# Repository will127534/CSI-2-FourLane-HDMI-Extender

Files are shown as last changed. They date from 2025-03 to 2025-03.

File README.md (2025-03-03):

# CSI-2-FourLane-HDMI-Extender
A simple MIPI CSI-2 extender with 4-lane support through HDMI cable

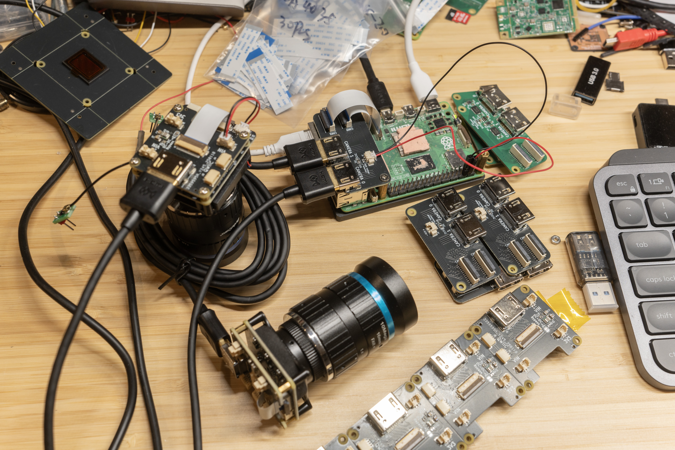
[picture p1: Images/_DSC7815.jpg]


## Hardware
Technically, this isn’t supposed to work, but it kind of does. It relies on HDMI cables with Ethernet support to provide the fifth differential pair needed to transmit 4-lane MIPI signals through the HDMI cable.

The board is very simple. The receiver can either use the 3.3V from the FPC cable or an external power input to supply the HDMI connector’s power output. The HDMI connector location matches the USB connector on the Raspberry Pi 5 to simplify case design.

The transmitter board has a DC-DC step-down converter with a 3.3V output and a bypass option to power camera boards. For the StarlightEye (which needs a 5V input), there is also a connector that taps into the HDMI power input to supply power—this could also power something else, like an LED light source. Additionally, there is a QWIIC connector for sideband communication. Finally, the board’s form factor includes a cutout for the OneInchEye 2.0.

## Notes

This project came about because GMSL2 was too difficult to implement, and I needed something to extend my 4-lane MIPI cameras. If you’re reading this, you probably already know there are a few HDMI extender boards for MIPI cameras out there. However, most only support 2-lane MIPI, while I specifically needed 4-lane MIPI.

Where’s the catch? The standard HDMI cable only has four high-speed differential pairs, so that’s typically not enough for 4-lane MIPI (which requires 4 data pairs + 1 clock pair). However, HDMI includes an extension standard that reuses the HPD and UTILITY pins on the connector for a fifth differential pair called HEAC. This pair is meant for a bi-directional higher-speed sideband signal for Ethernet or Audio. Spec-wise, it doesn't have to carry signals as high-speed as the main video data. However, from a manufacturing standpoint, it’s often just as capable, because many manufacturers use the same type of differential pair cable for the fifth pair. (See [this teardown video by ChargerLab ](https://www.youtube.com/watch?v=UTeQvG3jk0k) as an example.)

For testing, I used the Cable Matters 2-Pack Ultra Thin HDMI Cable series; the 6-ft version is the maximum length that can run both the OneInchEye and StarlightEye at 1440 Mbps/lane with 4-lane MIPI.

Note: If you are using my IMX585 driver, you must lower the link speed from 1782 Mbps/lane to 1440 Mbps/lane by changing [this](https://github.com/will127534/imx585-v4l2-driver/blob/main/imx585.c#L210) line to 0x03.

Lastly, I did try using MIPI redrivers and retimers from [Ti](https://www.ti.com/product/SN65DPHY440SS) and [Diodes](https://www.diodes.com/part/view/PI2MEQX2505). The receiver board was originally designed with an active redriver/retimer (both parts are conveniently pin-to-pin compatible). However, due to the board’s pin layout, the differential pairs would need a polarity swap, and TI’s retimer wouldn’t work, even with [this register](https://e2e.ti.com/support/interface-group/interface/f/interface-forum/1187578/sn65dphy440ss-in-a-csi-application-is-it-possible-to-invert-n-and-p-on-both-sides-of-t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) configured. As for the redriver, for some reason I couldn’t get it to work well with a 6-ft cable—only with a very short HDMI cable. The redriver is polarity-invariant, but even after playing around with the different tuning options, it just didn’t seem to work reliably. Suggestions are welcome in the issues/comments section.

## Footnotes

* Gerber, BOM, and CPL files for JLCPCB are under /Gerber and /bom in each Transmitter and Receiver board folder.
* [Interactive BOM for Receiver](https://htmlpreview.github.io/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) [(provided by InteractiveHtmlBom)
](https://github.com/openscopeproject/InteractiveHtmlBom)
* [Interactive BOM for Transmitter](https://htmlpreview.github.io/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) [(provided by InteractiveHtmlBom)
](https://github.com/openscopeproject/InteractiveHtmlBom)
* Yes It still supports 2-lane MIPI cameras (tested with the IMX708 Raspberry Pi Camera V3).
* I have almost no intention of selling this on Tindie, because I can already imagine users who don’t fully understand the details running into troubles and complaining about it.
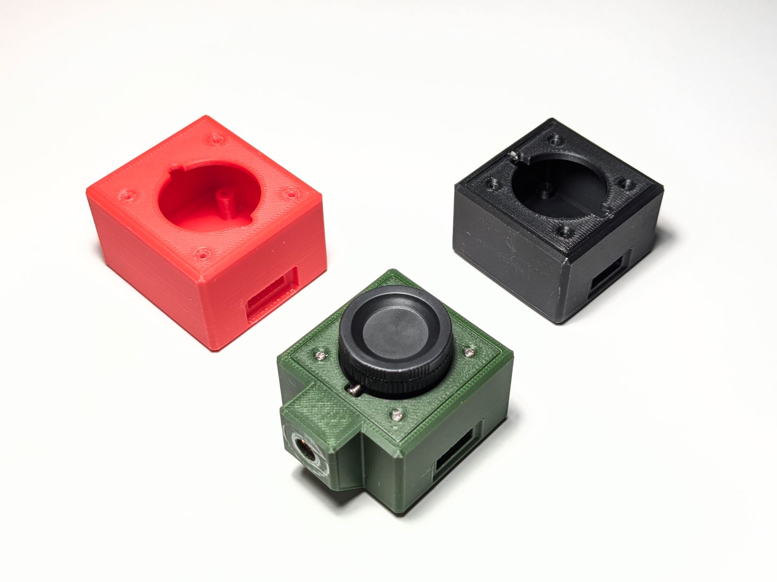
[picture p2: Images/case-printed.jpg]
* [@VoeGalore](https://github.com/VoeGalore/CSI-2-FourLane-HDMI-Extender) made 3D-printable cases for using the transmitter board with starlighteye(IMX585), oneincheye(IMX283), and Camera Module V3. STL files are under /case-STL in each folders. Additional hardware might be needed (M2x16 screws, M2x6 screws, M2 threaded insert, 1/4-20 threaded insert).

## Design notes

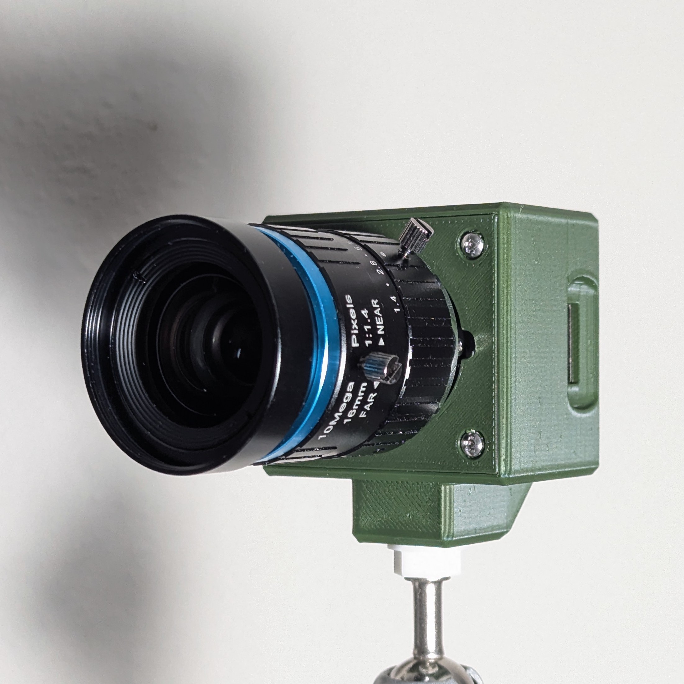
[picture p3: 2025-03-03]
Images/case-starlighteye-mounted.jpg

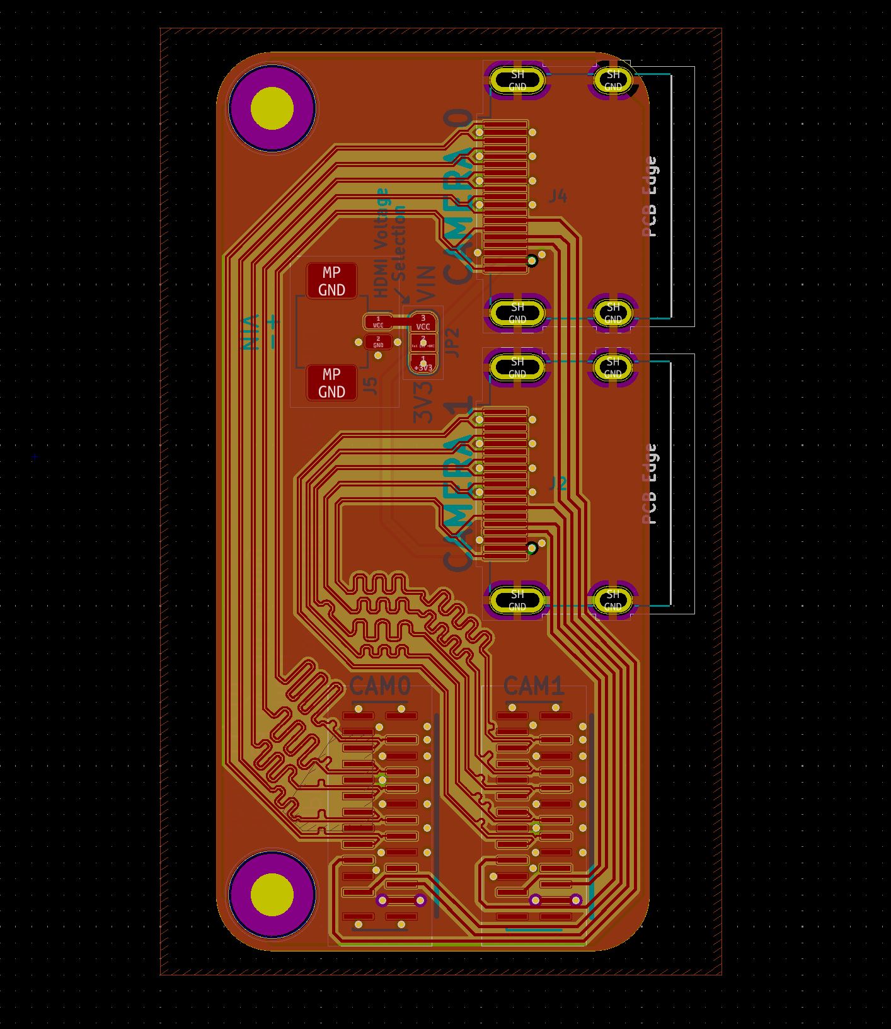
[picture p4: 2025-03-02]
Receiver/PCB.jpg

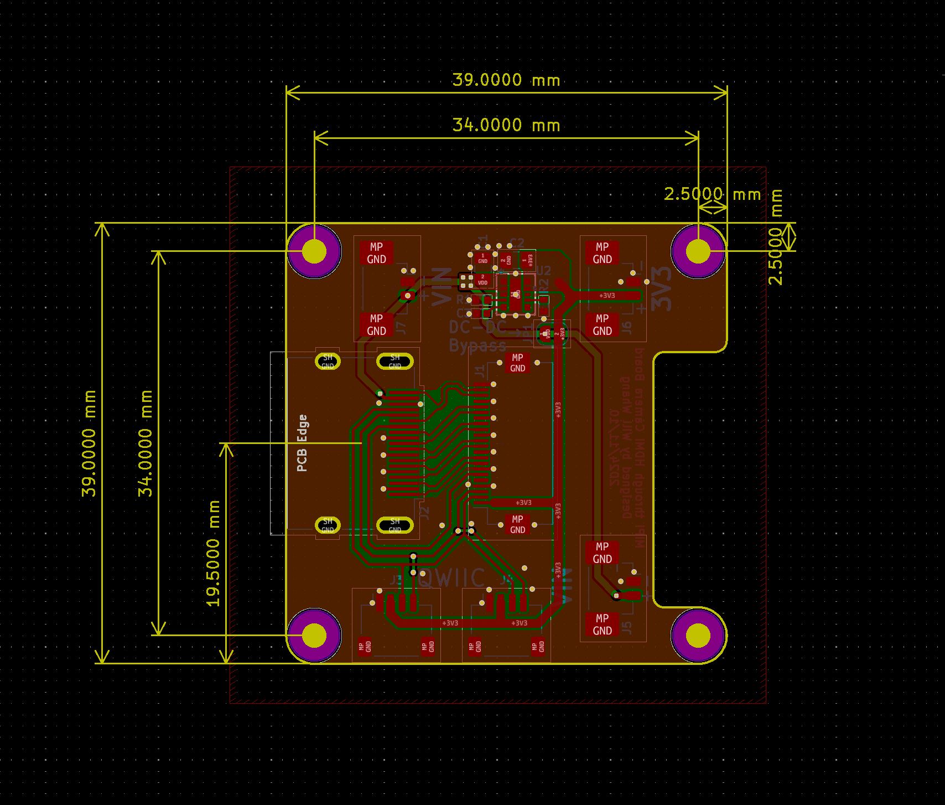
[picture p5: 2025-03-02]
Transmitter/PCB.jpg

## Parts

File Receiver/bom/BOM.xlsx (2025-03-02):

Comment | Designator | Footprint | JLCPCB Part #（optional）
HDMI-019S | J4,J2 | HDMI_A_Molex_208658-1001_Horizontal | C111617
Conn_01x22_Shielded | J1,J3 | TF3822S05SV830 | C6552695
Conn_01x02_Shielded | J5 | Molex_PicoBlade_53261-0271_1x02-1MP_P1.25mm_Horizontal | C177225

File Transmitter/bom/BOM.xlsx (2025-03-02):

Comment | Designator | Footprint | JLCPCB Part #（optional）
Conn_01x02_Shielded | J7,J6,J5 | Molex_PicoBlade_53398-0271_1x02-1MP_P1.25mm_Vertical | C122410
Conn_01x04_Shielded | J4,J3 | JST_SH_SM04B-SRSS-TB_1x04-1MP_P1.00mm_Horizontal | C160404
TPSM82902SISR | U2 | uSIP11_SIS_TEX | C6339351
Conn_01x22_Shielded | J1 | Hirose_FH12-22S-0.5SH_1x22-1MP_P0.50mm_Horizontal | C597981
40.2K | R1 | R_0402_1005Metric
22uF | C2 | C_0805_2012Metric
10uF | C3 | C_0402_1005Metric
10uF | C1 | C_0805_2012Metric
HDMI_A_1.4 | J2 | HDMI_A_Molex_208658-1001_Horizontal | C111617

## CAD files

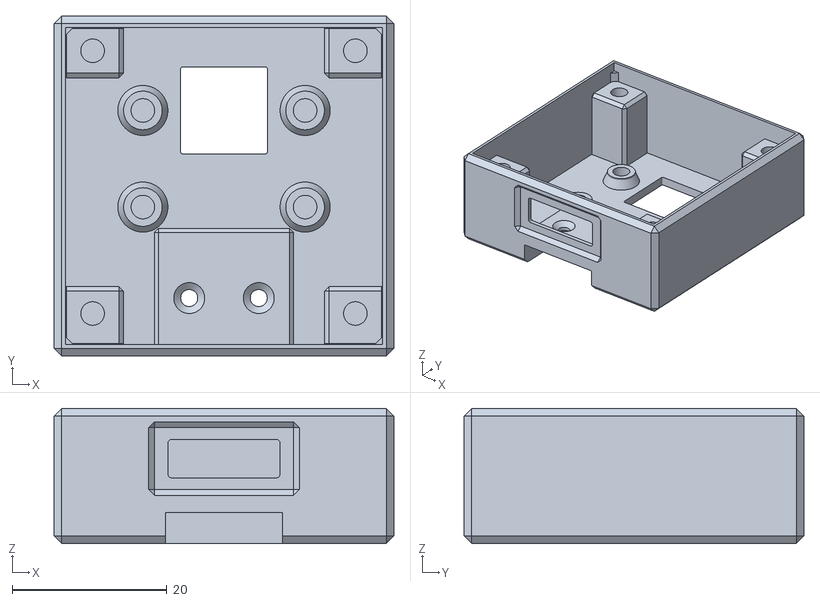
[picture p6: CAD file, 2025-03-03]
case-STL/cameraV3/Case for V3 - main.stl
44.0 x 44.0 x 17.5

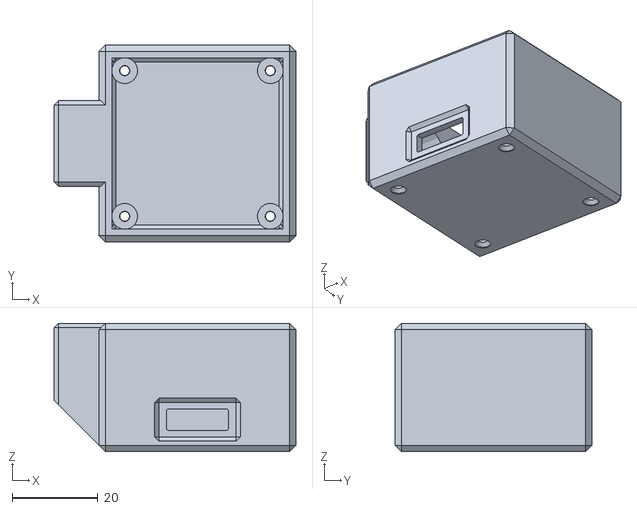
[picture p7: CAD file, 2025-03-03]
case-STL/oneincheye/case for oneincheye - high standoff - with 1_4-20 mounting.stl
56.5 x 46.0 x 30.0

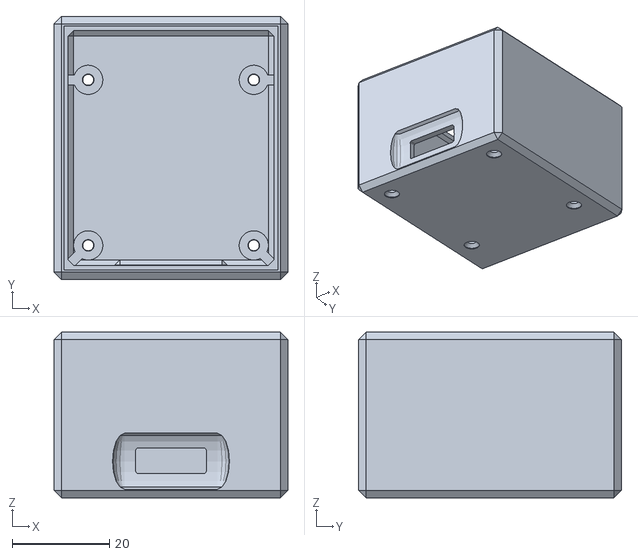
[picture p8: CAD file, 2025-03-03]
case-STL/starlighteye/case for starlighteye.stl
48.0 x 54.0 x 34.0

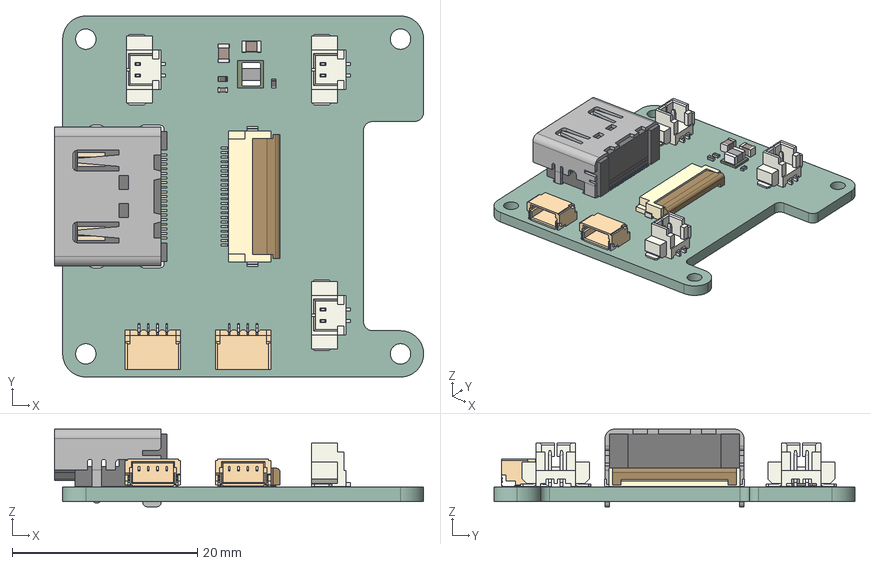
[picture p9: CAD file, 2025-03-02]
Transmitter/Transmitter.step
39.9 x 39.0 x 8.39 mm
Molex_53398_0271 x 3
SM04B-SRSS-TB(LFSN) x 2
R_0402_1005Metric x 2
SIS0011A_ASM
Hirose_FH12_xxS_0_5SH_Parametric_v0_1
C_0805_2012Metric x 2
C_0402_1005Metric
HDMI_A_Molex_208658-1001_Horizontal
MIPItoHDMI_Buffered_PCB

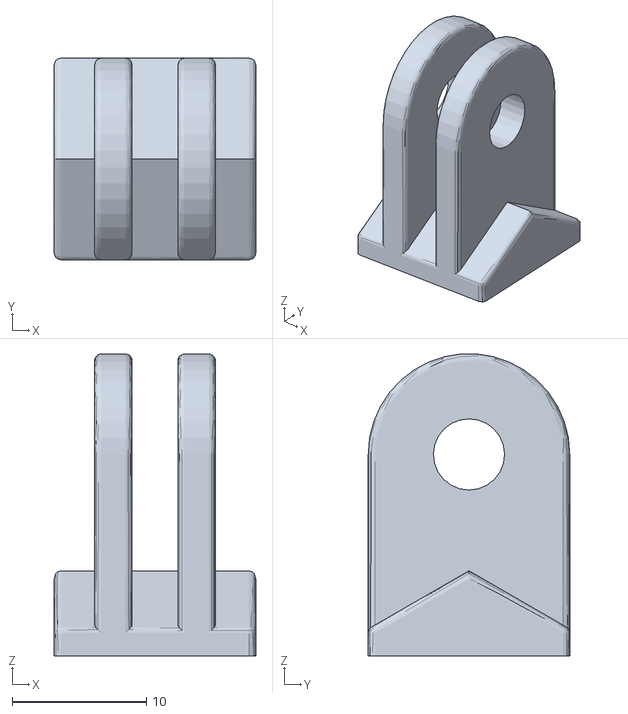
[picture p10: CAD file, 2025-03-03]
case-STL/cameraV3/Case for V3 - gopro mount ear.stl
15.0 x 15.0 x 22.5

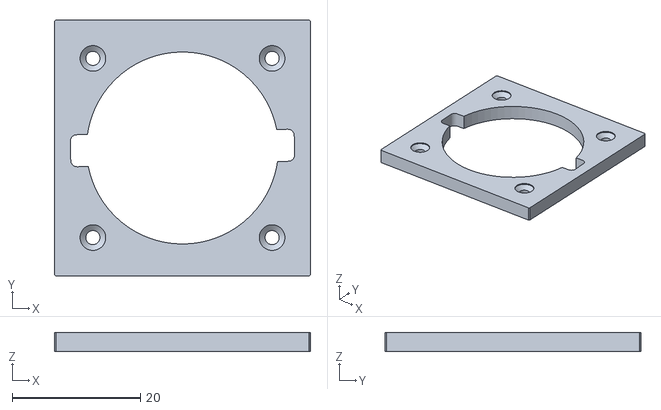
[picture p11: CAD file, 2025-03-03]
case-STL/oneincheye/faceplate for oneincheye.stl
40.0 x 40.0 x 3.00

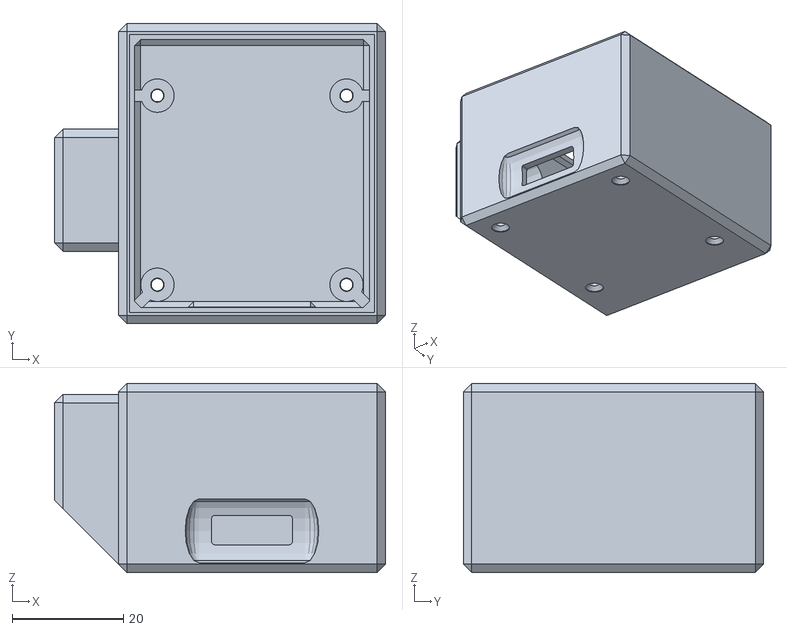
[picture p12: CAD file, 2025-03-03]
case-STL/starlighteye/case for starlighteye - with 1_4-20 mounting.stl
59.5 x 54.0 x 34.0

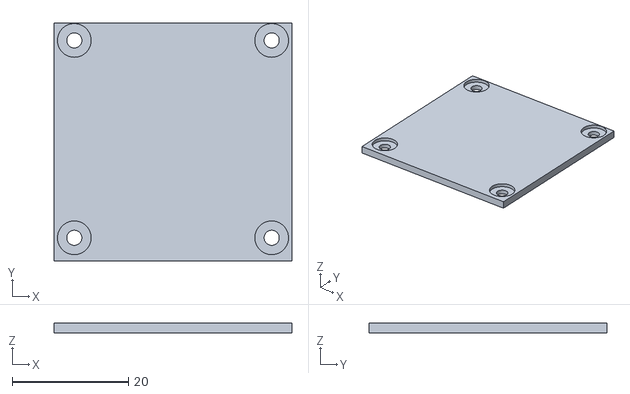
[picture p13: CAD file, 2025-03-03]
case-STL/cameraV3/Case for V3 - backplate.stl
41.0 x 41.0 x 1.70

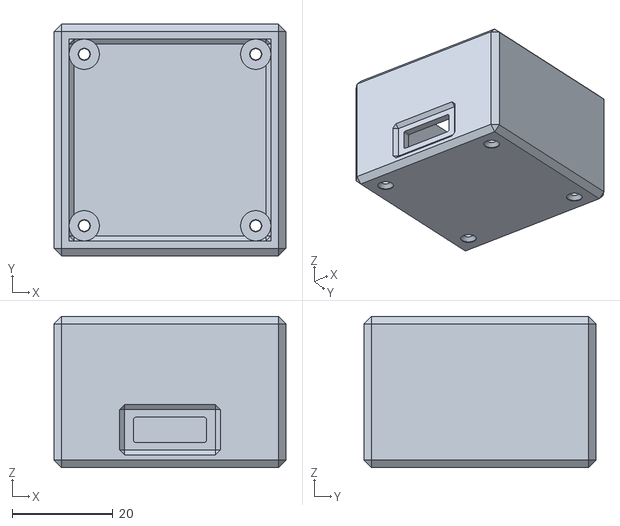
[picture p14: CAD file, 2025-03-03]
case-STL/oneincheye/case for oneincheye - high standoff.stl
46.0 x 46.0 x 30.0

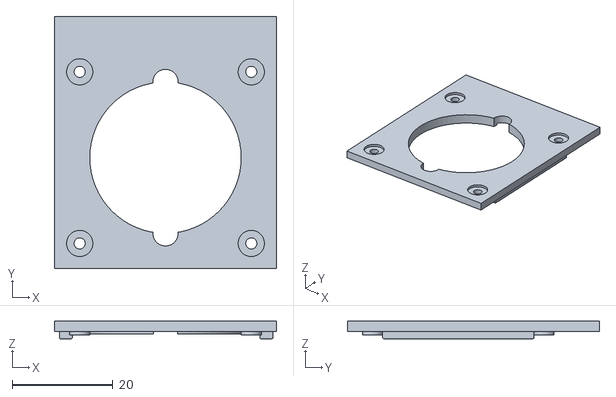
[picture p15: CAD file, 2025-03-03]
case-STL/starlighteye/faceplate for starlighteye.stl
44.0 x 50.0 x 3.50

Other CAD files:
case-STL/oneincheye/case for oneincheye - low standoff.stl

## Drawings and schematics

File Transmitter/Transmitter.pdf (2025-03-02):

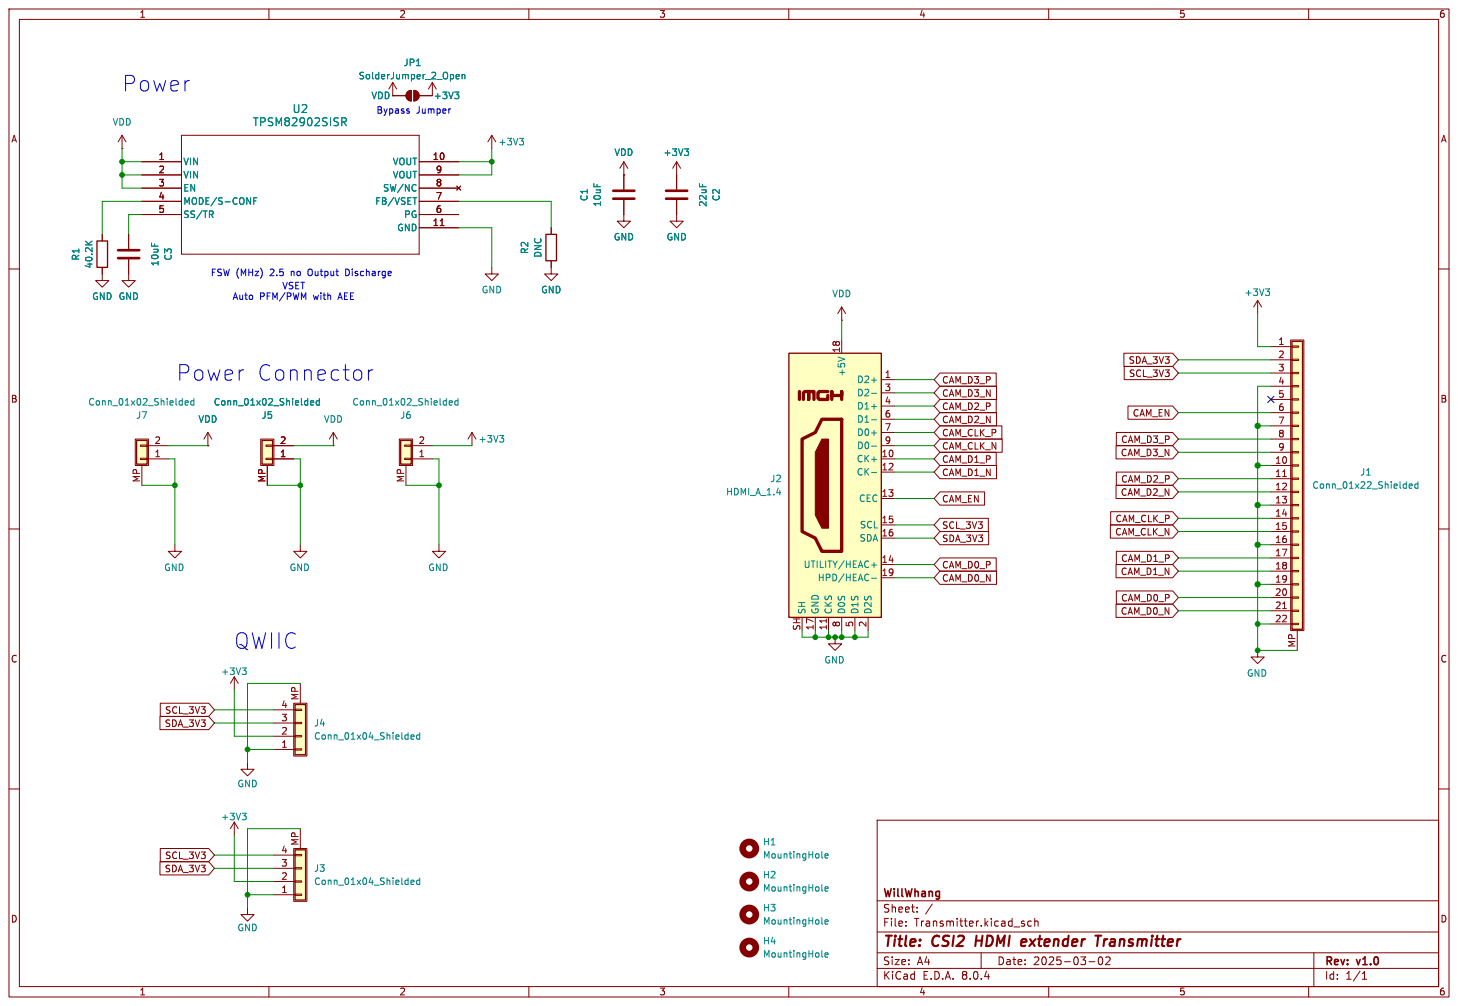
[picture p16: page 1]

Bypass Jumper VSET Auto PFM/PWM with AEE U2 TPSM82902SISR

FSW (MHz) 2.5 no Output Discharge

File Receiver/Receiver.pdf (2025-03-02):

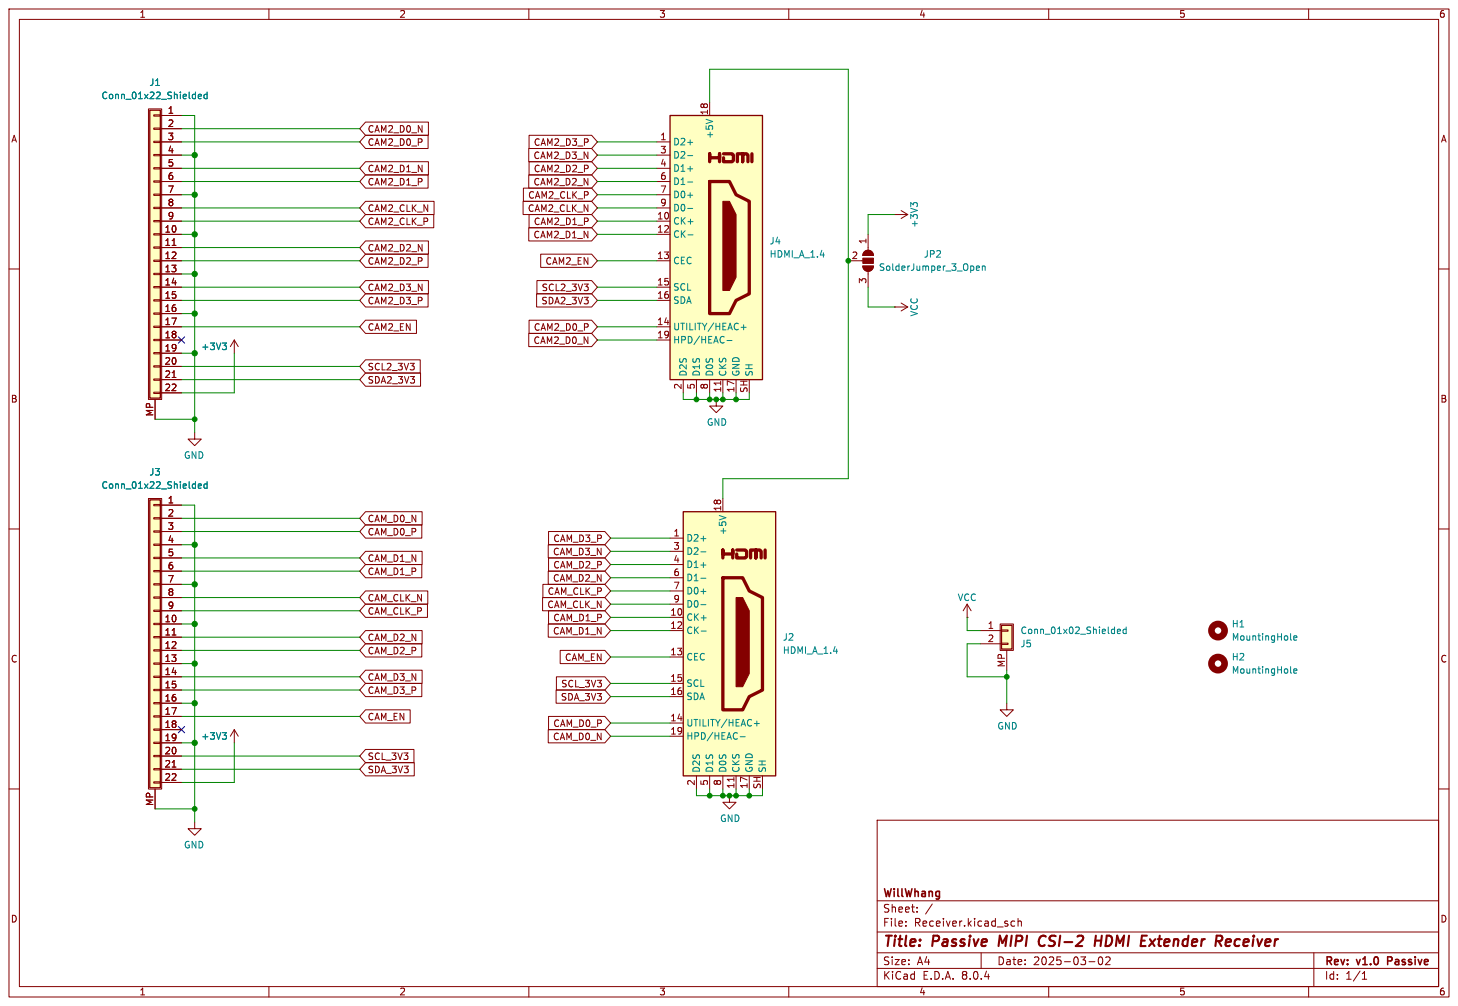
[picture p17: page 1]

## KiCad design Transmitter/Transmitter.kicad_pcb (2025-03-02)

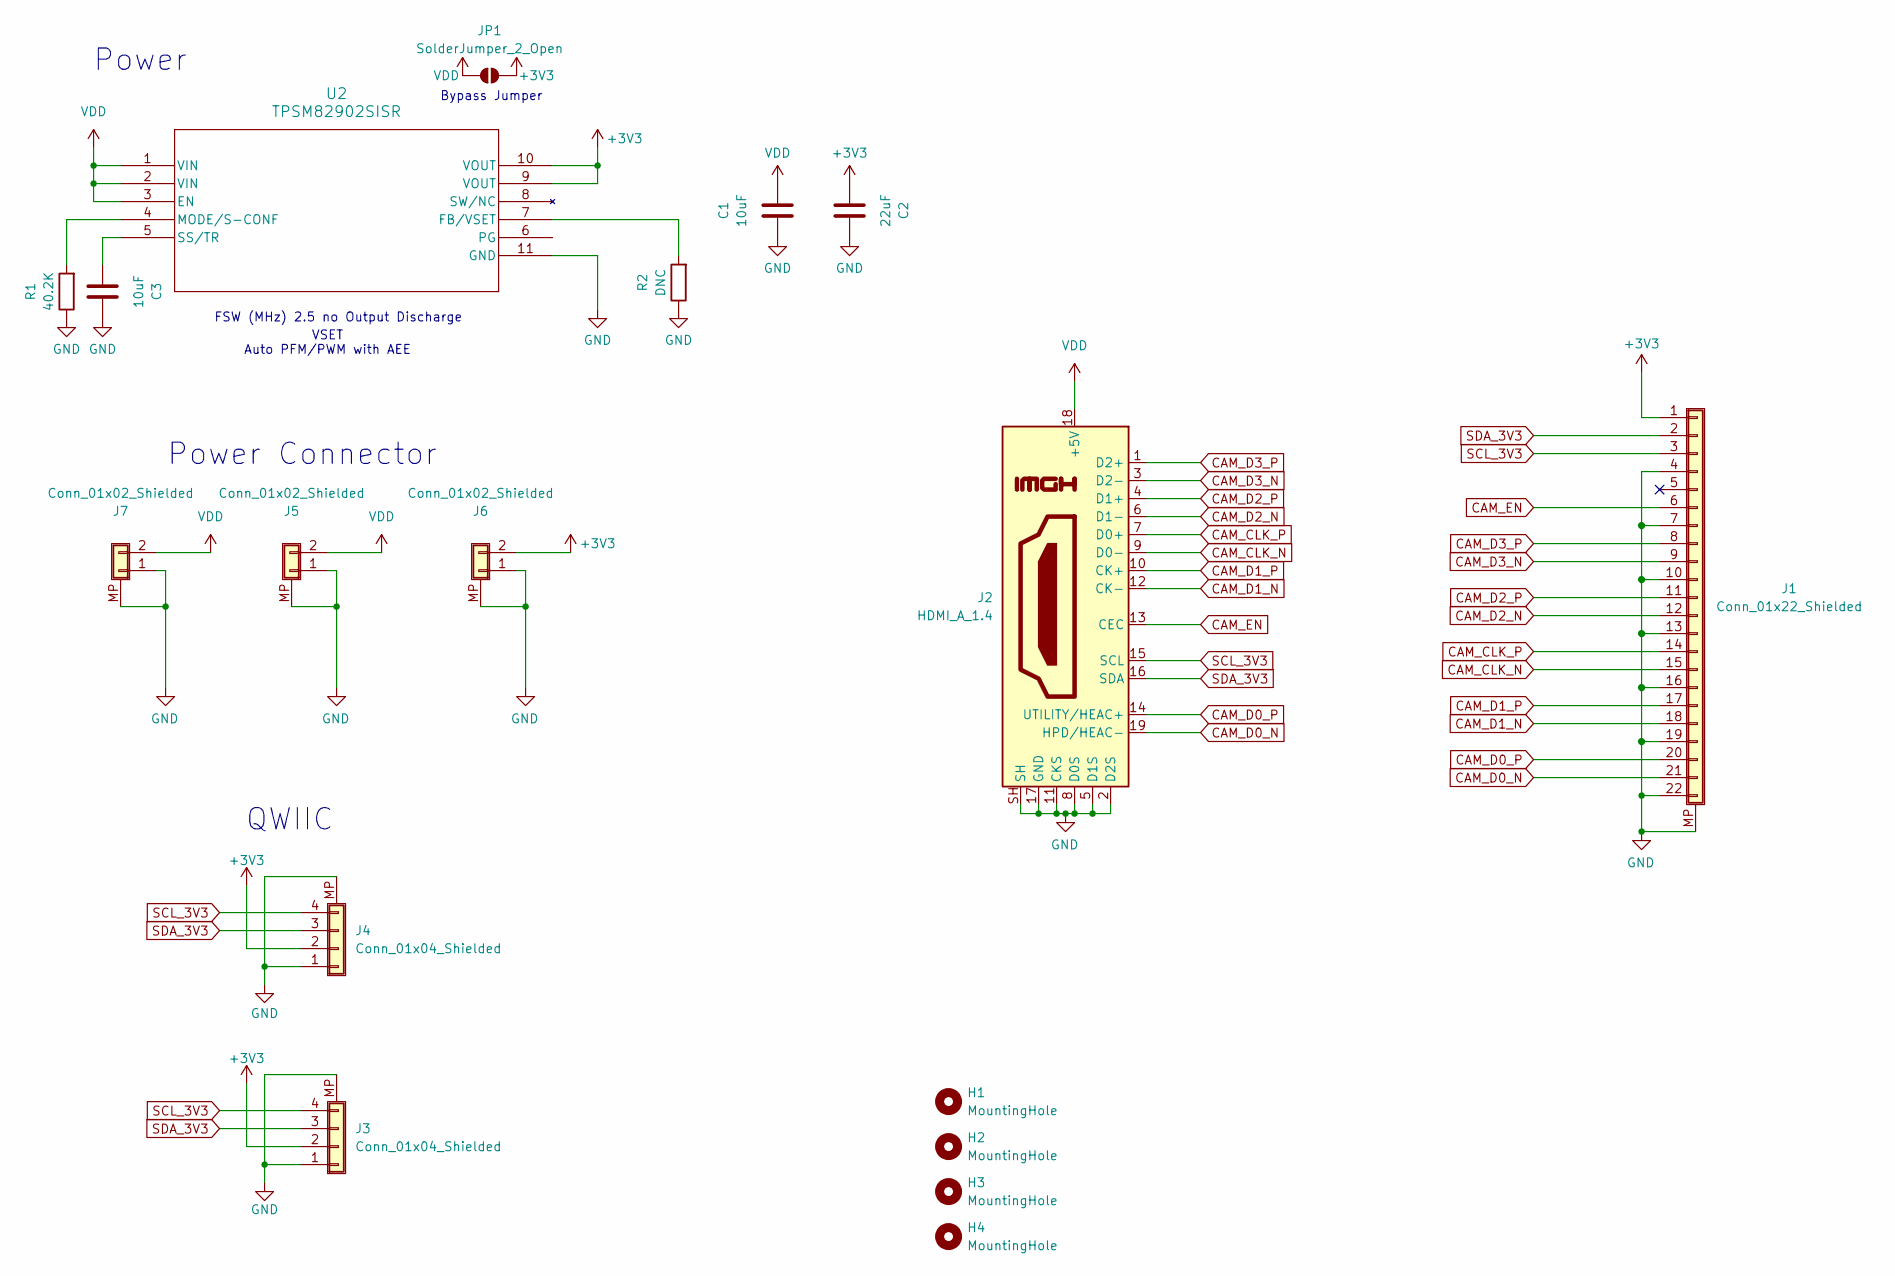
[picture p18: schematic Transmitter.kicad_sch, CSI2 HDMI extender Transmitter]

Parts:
C1: 10uF; C_0805_2012Metric
C2: 22uF; C_0805_2012Metric
C3: 10uF; C_0402_1005Metric
H1, H2, H3, H4: MountingHole; MountingHole_2.2mm_M2
J1: Conn_01x22_Shielded; Hirose_FH12-22S-0.5SH_1x22-1MP_P0.50mm_Horizontal
J2: HDMI_A_1.4; HDMI_A_Molex_208658-1001_Horizontal
J3, J4: Conn_01x04_Shielded; JST_SH_SM04B-SRSS-TB_1x04-1MP_P1.00mm_Horizontal
J5, J6, J7: Conn_01x02_Shielded; Molex_PicoBlade_53398-0271_1x02-1MP_P1.25mm_Vertical
JP1: SolderJumper_2_Open; SolderJumper-2_P1.3mm_Open_RoundedPad1.0x1.5mm
R1: 40.2K; R_0402_1005Metric
R2: DNC; R_0402_1005Metric
U2: TPSM82902SISR; uSIP11_SIS_TEX

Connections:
+3V3: C2.1, J1.1, J3.2, J4.2, J6.2, JP1.2 (B), U2.9 (VOUT), U2.10 (VOUT)
CAM_CLK_N: J1.15, J2.9 (D0-)
CAM_CLK_P: J1.14, J2.7 (D0+)
CAM_D0_N: J1.21, J2.19 (HPD/HEAC-)
CAM_D0_P: J1.20, J2.14 (UTILITY/HEAC+)
CAM_D1_N: J1.18, J2.12 (CK-)
CAM_D1_P: J1.17, J2.10 (CK+)
CAM_D2_N: J1.12, J2.6 (D1-)
CAM_D2_P: J1.11, J2.4 (D1+)
CAM_D3_N: J1.9, J2.3 (D2-)
CAM_D3_P: J1.8, J2.1 (D2+)
CAM_EN: J1.6, J2.13 (CEC)
GND: C1.1, C2.2, C3.2, J1.4, J1.7, J1.10, J1.13, J1.16, J1.19, J1.22, J1.MP (Shield), J2.2 (D2S), J2.5 (D1S), J2.8 (D0S), J2.11 (CKS), J2.17 (GND), J2.SH, J3.1, J3.MP (Shield), J4.1, J4.MP (Shield), J5.1, J5.MP (Shield), J6.1, J6.MP (Shield), J7.1, J7.MP (Shield), R1.1, R2.1, U2.11 (GND)
unnamed: R2.2, U2.7 (FB/VSET)
unnamed: R1.2, U2.4 (MODE/S-CONF)
unnamed: C3.1, U2.5 (SS/TR)
SCL_3V3: J1.3, J2.15 (SCL), J3.4, J4.4
SDA_3V3: J1.2, J2.16 (SDA), J3.3, J4.3
VDD: C1.2, J2.18 (+5V), J5.2, J7.2, JP1.1 (A), U2.1 (VIN), U2.2 (VIN), U2.3 (EN)

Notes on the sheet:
Power Connector
FSW (MHz) 2.5 no Output Discharge
Power
VSET Auto PFM/PWM with AEE
QWIIC
Bypass Jumper

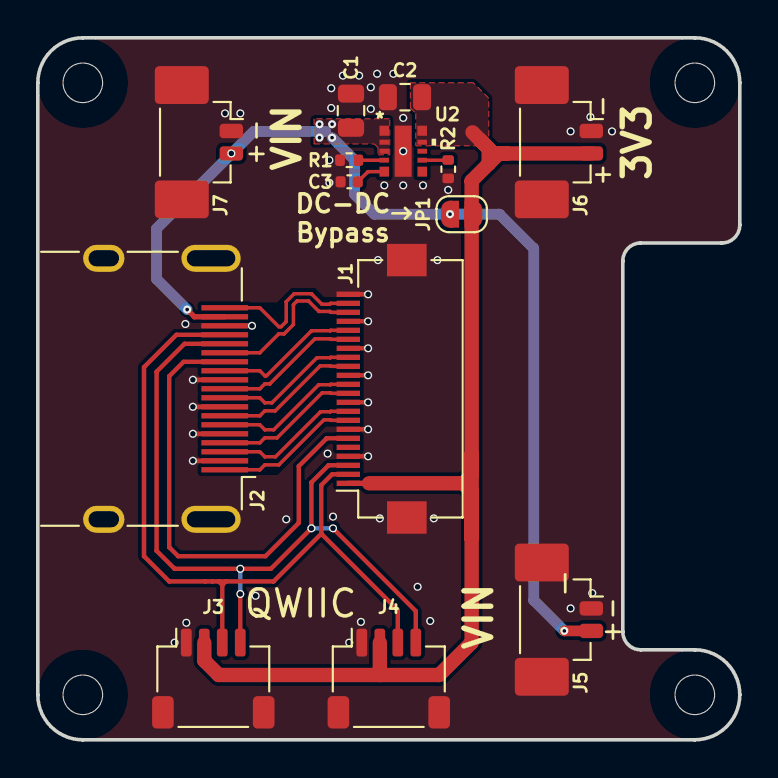
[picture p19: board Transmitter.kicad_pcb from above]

Board: 2 copper layers, 39.0 x 39.0 mm, 18 parts (0 on the bottom side), 19 nets.

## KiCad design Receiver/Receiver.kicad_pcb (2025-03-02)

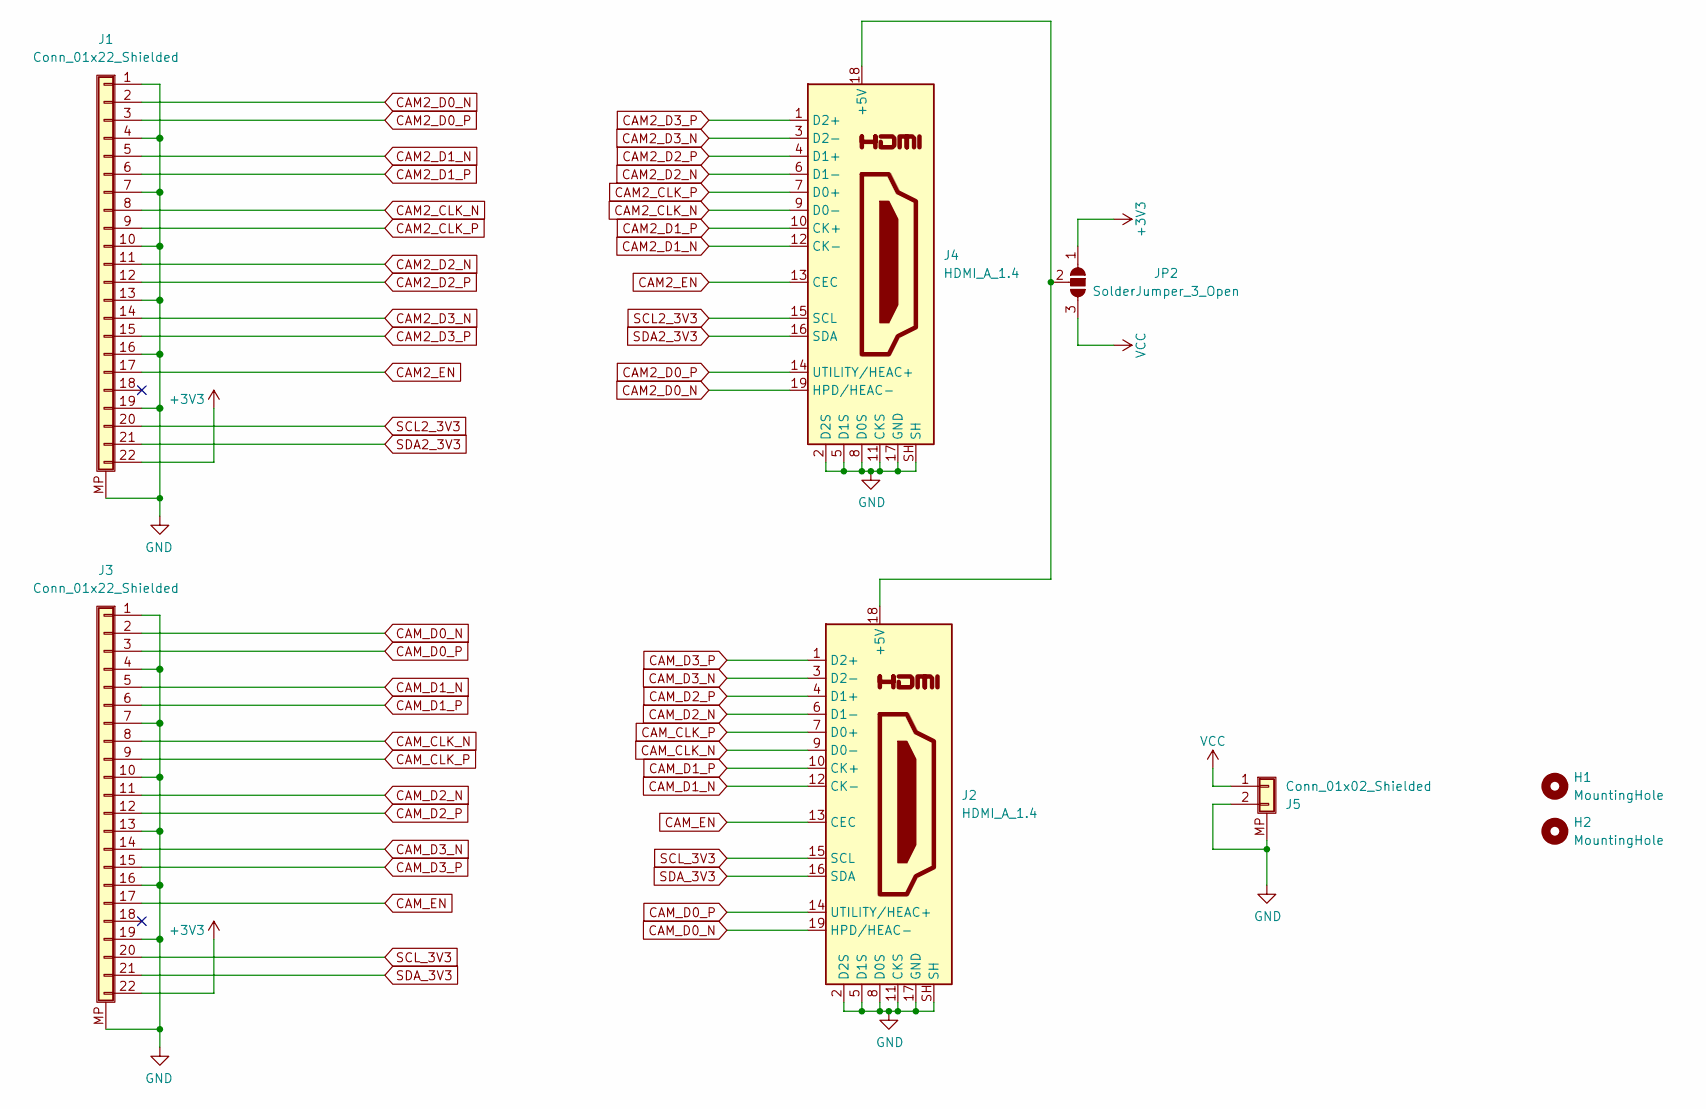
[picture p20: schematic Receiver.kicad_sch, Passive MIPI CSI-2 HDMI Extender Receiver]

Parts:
H1, H2: MountingHole; MountingHole_2.7mm_M2.5
J1, J3: Conn_01x22_Shielded; TF3822S05SV830
J2, J4: HDMI_A_1.4; HDMI_A_Molex_208658-1001_Horizontal
J5: Conn_01x02_Shielded; Molex_PicoBlade_53261-0271_1x02-1MP_P1.25mm_Horizontal
JP2: SolderJumper_3_Open; SolderJumper-3_P1.3mm_Open_RoundedPad1.0x1.5mm_NumberLabels

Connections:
+3V3: J1.22, J3.22, JP2.1 (A)
CAM2_CLK_N: J1.8, J4.9 (D0-)
CAM2_CLK_P: J1.9, J4.7 (D0+)
CAM2_D0_N: J1.2, J4.19 (HPD/HEAC-)
CAM2_D0_P: J1.3, J4.14 (UTILITY/HEAC+)
CAM2_D1_N: J1.5, J4.12 (CK-)
CAM2_D1_P: J1.6, J4.10 (CK+)
CAM2_D2_N: J1.11, J4.6 (D1-)
CAM2_D2_P: J1.12, J4.4 (D1+)
CAM2_D3_N: J1.14, J4.3 (D2-)
CAM2_D3_P: J1.15, J4.1 (D2+)
CAM2_EN: J1.17, J4.13 (CEC)
CAM_CLK_N: J2.9 (D0-), J3.8
CAM_CLK_P: J2.7 (D0+), J3.9
CAM_D0_N: J2.19 (HPD/HEAC-), J3.2
CAM_D0_P: J2.14 (UTILITY/HEAC+), J3.3
CAM_D1_N: J2.12 (CK-), J3.5
CAM_D1_P: J2.10 (CK+), J3.6
CAM_D2_N: J2.6 (D1-), J3.11
CAM_D2_P: J2.4 (D1+), J3.12
CAM_D3_N: J2.3 (D2-), J3.14
CAM_D3_P: J2.1 (D2+), J3.15
CAM_EN: J2.13 (CEC), J3.17
GND: J1.1, J1.4, J1.7, J1.10, J1.13, J1.16, J1.19, J1.MP (Shield), J2.2 (D2S), J2.5 (D1S), J2.8 (D0S), J2.11 (CKS), J2.17 (GND), J2.SH, J3.1, J3.4, J3.7, J3.10, J3.13, J3.16, J3.19, J3.MP (Shield), J4.2 (D2S), J4.5 (D1S), J4.8 (D0S), J4.11 (CKS), J4.17 (GND), J4.SH, J5.2, J5.MP (Shield)
unnamed: J2.18 (+5V), J4.18 (+5V), JP2.2 (C)
SCL2_3V3: J1.20, J4.15 (SCL)
SCL_3V3: J2.15 (SCL), J3.20
SDA2_3V3: J1.21, J4.16 (SDA)
SDA_3V3: J2.16 (SDA), J3.21
VCC: J5.1, JP2.3 (B)

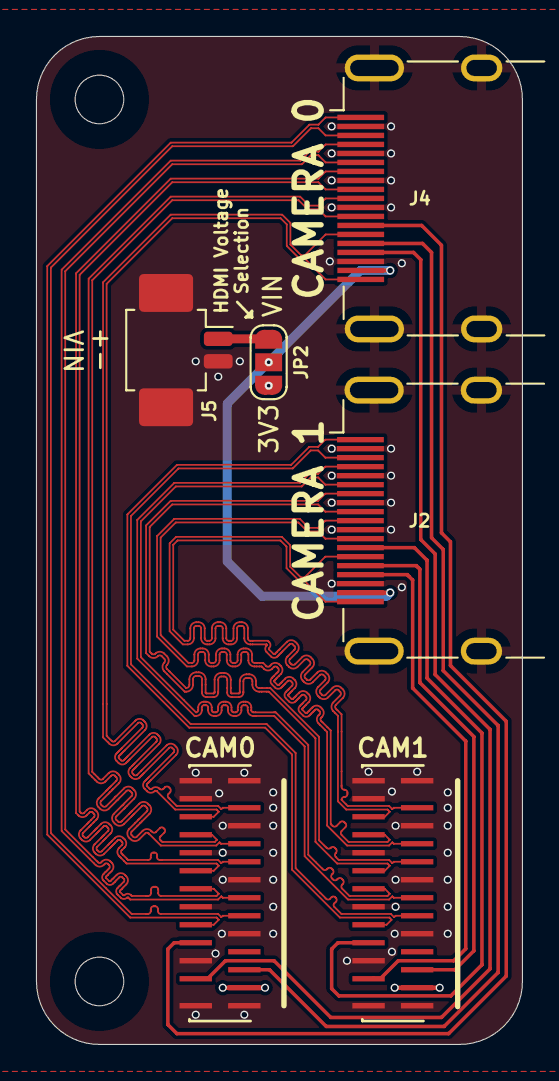
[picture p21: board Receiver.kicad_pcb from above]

Board: 4 copper layers, 27.0 x 56.0 mm, 8 parts (0 on the bottom side), 30 nets.

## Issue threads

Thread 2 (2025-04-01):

Could it be DisplayPort Extender ?

TooGuech, 2025-04-01:
Hi, first thank you for your sharing, i'm looking for something to transport the CSI 4 lanes via every thing else than the 22 rubban cable.

Have you give a try with DisplayPort ?

already 4 lanes + 1 Aux ( maybe for clock ) + maybe 2 pins for SCCB ( 13, 14, 18, 19 pins ? ) + Power + GND

Thank you in advance.

@+

will127534, 2025-04-02:
I have not try Displayport and will probably not given that I have HDMI cables working already.

Closed 2025-04-02.

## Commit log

2025-03-02 Update Filename
    [BOM.xlsx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]
2025-03-03 Add photos of 3D-printed cases
2025-03-03 Add STL files of 3D printed cases
    [case for oneincheye - high standoff - with 1_4-20 mounting.stl, case for oneincheye - high standoff.stl, case for oneincheye - low standoff.stl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]
2025-03-03 added 3D printed case in footnote
2025-03-03 Add files for 3D printed cases
    [Case for V3 - backplate.stl, Case for V3 - gopro mount ear.stl, Case for V3 - main.stl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]
2025-03-03 Update README.md - showing image for the case
